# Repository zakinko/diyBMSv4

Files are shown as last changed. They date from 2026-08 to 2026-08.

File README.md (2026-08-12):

# diyBMS v4

Version 4 of the diyBMS

Do it yourself battery management system for Lithium ion battery packs/cells

More discussion [Open Energy Monitor Forum](https://community.openenergymonitor.org/c/hardware/diybms/53)

If you are looking for version 3 (obsolete) of this project take a look [here](https://github.com/stuartpittaway/diyBMS)

THIS REPOSITORY CONTAINS THE HARDWARE FOR THE SYSTEM

---

## About this branch — keeping the boards orderable

This is a fork of [stuartpittaway/diyBMSv4](https://github.com/stuartpittaway/diyBMSv4).
Every LCSC part number in every BOM here was checked against the JLCPCB parts API,
and **eight of the eleven boards could not be ordered as they stood** - parts at zero
stock, parts the API reports as discontinued, and on one board a BOM cell holding two
part numbers at once.  This branch fixes what can be fixed by changing a part number,
and says plainly where that is not enough.

**What is maintained**

* Part numbers that JLCPCB no longer stocks are replaced, where an equivalent exists
* Where the same part number also exists in the Basic library, it is used - Basic and
  Preferred parts carry no per-type setup fee
* Where no equivalent exists, the part is left alone and the reason is in the commit

**What is not**

* **Nothing here is tested on hardware.**  These are file-level changes checked
  against the schematic, the netlist, the datasheets and the parts API, and no
  further.  Reports from anyone who builds one are very welcome
* The circuits are not being redesigned.  Where a board has a weakness that needs a
  layout change - the ESP8266 controller has no decoupling capacitors at all, and no
  clamp on the ESP's RX line - it is written down, not fixed

**Two boards cannot be reproduced exactly, and are not pretended otherwise**

V440 and V450 both use AZ432 for their voltage reference.  Diodes discontinued it -
the datasheet is stamped OBSOLETE - USE AZ431L - and every SOT-23 shunt reference
still stocked is 1.240V rather than 1.250V.  On both boards that reference sets the
cell measurement, so substituting it shifts every reading by 0.8% with no warning.

D1 is therefore left as AZ432 on both.  Order the board without it and fit it by
hand; it is out of production but was made in volume and still turns up.  Anyone who
would rather have a current part than an exact V440/V450 should look at a revision
that designs AZ431L in and changes the firmware constant to match.

V400 is untouched for a different reason: its schematic carries no LCSC part numbers
at all and no BOM is generated from it.  Its parts are listed in a separate
spreadsheet, so making it orderable means building a BOM rather than editing one.

Upstream's own README follows unchanged.

---

# Videos on how to use and build

[YouTube playlist](https://youtube.com/playlist?list=PLHhwQCDPuRcZW3u0jJucsiCCsUbNbMy-c) for DIYBMS videos

[Building & ordering the PCB from JLCPCB](https://youtu.be/E1OS0ZOmOT8)

If you order a PCB, please use my affiliate link to help support this project [JLCPCB](https://jlcpcb.com/RSZ)

# Support

If you find the BMS useful, please consider buying me a beer, check out Patron for more information

https://patreon.com/StuartP

# HARDWARE

This repository contains the hardware designs, generally in KiCad format.  Unless you are changing the design, you don't need to use/install KiCad, just use the precompiled files.

The folder structure in the repository contains:

## Controller Designs
* ControllerCircuit - ESP32 controller board (newest design)
* ESP8266ControllerCircuit - [legacy] the circuit board for the legacy ESP8266 based controller

## Modules for Controller
* ModuleV490-AllInOne - Latest multi cell monitoring solution, recommended for 8 to 16S cell configurations.  No balancing, requires ModuleV490-PassiveBal passive balancer daughterboard if this is needed.
* ModuleV490-PassiveBal - daughter board for the V490 multi-cell monitoring solution, provides 200mA per cell balance current, heatsink and fan control.
* ModuleV450 - the latest SINGLE module design, using ATTINY1624 chip. Recommended for both hand soldering or mass production
* ModuleV440 - [legacy] the module circuit board V4.40, final board using ATTINY841 chip
* ModuleV400 - [legacy] the module circuit board V4.00, designed for easier hand soldering (larger parts)
* ModuleV421 - [legacy] the module circuit board V4.21, designed for mass production using JLCPCB assembly service

If you use this coupon code when you place a JLCPCB order

JLC-Stuart

and this link

https://jlcpcb.com/RSZ

you will get a discount and I get a very small amount of credit for every 30 orders, which helps to support the cost of prototyping new designs and adding new features.

### ESP32 Controller 

The latest version of the controller uses an ESP32 and supports CANBUS, RS485, SD CARD logging, relays, SSR outputs, multiple inputs, AVR programmer and much more.

Although the hardware is complete, not all features are usable from the software, this will be developed and improved over time to make use of the hardware.

[Bill of Materials](./ControllerCircuit/ComponentListBOM.md)

circuit board

### Module V4.50

The latest version of the module hardware uses the ATTINY1624 chip - part of the tinyAVR2 range.

This board requires an UPDI programmer/device - see the instructions in the code repository for how to program the boards once built.

The parts are no smaller than 0805 size (about 2mm!) which is probably the smallest size you want to attempt to hand solder.

circuit board

Specifications are similar to the V4.40 board.

### Module V4.40

V4.40 is the last board to use the ATTINY841 chip - V4.50 is the newest design if you are starting fresh.

circuit board

In addition, the hardware has a higher balance current, fuse and TVS diode to help with voltage spikes.  
Most importantly, an external crystal has been added to the micro controller (attiny841) which means the device is more reliable in low voltage situations.

The balance current for V4.40 modules is as follows:
* 1.27A at 4.2V (5.35W)
* 1.21A at 4.0V (4.84W)
* 1.13A at 3.75V (4.26W)

The module is physically larger than previous modules, this aids heat dispersal but also features a "snap off" external temperature daughter board for use in cell temperature monitoring.

You will also need to order [these parts](./ModuleV440/HandAssemblyParts.md)

# CODE/SOFTWARE

Software and code for the modules and controller can now be found in a seperate repo

For the latest controller (ESP32)
[diyBMSv4ESP32](https://github.com/stuartpittaway/diyBMSv4ESP32)

For the legacy controller (ESP8266)
[diyBMSv4Code](https://github.com/stuartpittaway/diyBMSv4Code)

# WARNING

This is a DIY product/solution so don’t use this for safety critical systems or in any situation where there could be a risk to life.  

There is no warranty, it may not work as expected or at all.

The use of this project is done so entirely at your own risk.  It may involve electrical voltages which could kill - if in doubt, seek help.

The use of this project may not be compliant with local laws or regulations - if in doubt, seek help.

# License

This work is licensed under a Creative Commons Attribution-NonCommercial-ShareAlike 2.0 UK: England & Wales License.

https://creativecommons.org/licenses/by-nc-sa/2.0/uk/

You are free to:
* Share — copy and redistribute the material in any medium or format
* Adapt — remix, transform, and build upon the material
The licensor cannot revoke these freedoms as long as you follow the license terms.

Under the following terms:
* Attribution — You must give appropriate credit, provide a link to the license, and indicate if changes were made. You may do so in any reasonable manner, but not in any way that suggests the licensor endorses you or your use.
* Non-Commercial — You may not use the material for commercial purposes.
* ShareAlike — If you remix, transform, or build upon the material, you must distribute your contributions under the same license as the original.
* No additional restrictions — You may not apply legal terms or technological measures that legally restrict others from doing anything the license permits.

Notices:
You do not have to comply with the license for elements of the material in the public domain or where your use is permitted by an applicable exception or limitation.

No warranties are given. The license may not give you all of the permissions necessary for your intended use. For example, other rights such as publicity, privacy, or moral rights may limit how you use the material.

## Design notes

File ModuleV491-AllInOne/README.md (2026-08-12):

# DIYBMS All-in-one 16S monitoring board

This is the hardware for the (up to) 16S monitoring board.

## Difference from V490

Same board, same firmware.  Only the fitted parts differ: the ones that could
no longer be ordered are replaced, and a few move to parts that cost nothing to
set up.  See the pull request that introduced this directory for the full list
and the reasoning.
This monitoring board replaces the individual cell monitoring boards used in the DIYBMS solution.  Several monitoring boards can be daisy-chained together to form larger battery packs.

You still require a DIYBMS ESP32 controller for this board to operate.

It uses an [STM32F030K6T6](https://www.st.com/en/microcontrollers-microprocessors/stm32f030k6.html) chip, with 32K flash and 4K RAM.

**WARNING**: This hardware is considered experimental & prototype, use at your own risk - it may not work as intended or at all.

## Background Information
### Software
The software for this board is available pre-compiled.  See this [link for details](https://github.com/stuartpittaway/diyBMSv4ESP32/tree/all-in-one/STM32All-In-One#readme)

Details are in the README on programming the STM32 chip for this PCB.

### KiCAD 7
This design uses KiCAD version 7.0.5.  Use the same or newer version for editing and viewing the files.  You don't need to install KiCAD if you just wish to build/order one.

### JLCPCB
The files in this repository will create a PCB and design files suitable for "almost" full construction at JLCPCB.  Some manual soldering will still be required for the connectors and cabling.

Look inside the "export" folder for the relevant production files.  You will need these files for the construction:

* module_16s_gerbers.zip
* Module_16S_bom_jlc.csv
* Module_16S_cpl_jlc.csv

Support this project by using JLCPCB referral link
https://jlcpcb.com/RSZ
when registering for the first time.

# READ THIS FIRST - IMPORTANT

Before construction of the PCB you must determine what battery cells you wish to monitor and a suitable cell voltage range.

The PCB design has options for two voltage ranges, determined by parts U2 and U6.  *ONLY ONE OF THESE CHIPS MUST BE FITTED*

The design uses a MAX14921 chip, this has a maximum of 16 cells and **65V** total battery voltage - do not exceed.

## LIFEPO4 cells up to 4.00V maximum

Use part U2, a Microchip voltage reference "MCP1501-40E/SN".  This is a 4.096V ±0.1% reference chip.

This part is available on JLCPCB as part number C1575589.

The pick and place file (CPL file) contains the part placement for this chip by default.  No further changes are required, except to double-check the order screens from JLCPCB.

Do not install part U6.

*This option has been tested by the author as working*

## Cell voltages up to 4.50V maximum

This is all 18650 style cell voltage chemistry - normally with a maximum of 4.25V.  This configuration can also be used with LIFEPO4 cells with voltages below 4.50V.

Use part U6, a Microchip voltage reference "MCP1502T-45E/CHY".   This is a 4.500V ±0.1% reference chip.

This part is NOT available from JLCPCB.  This part must be obtained from [other sources](https://www.digikey.co.uk/en/products/detail/microchip-technology/MCP1502T-45E-CHY/16549208) and **MANUALLY** soldered onto the board.  Note this is a very small chip (SOT-23-6) and difficult to solder.

Edit the pick and place (CPL file) before upload to JLCPCB to remove the line marked "U2".

Do not install part U2.

*This option has NOT been tested by the author, please feedback if you decide to experiment*

## BATTERY VOLTAGES ABOVE 24V & MINIMUM BELOW 12V

If you have an unusual Lithium cell chemistry where the maximum battery voltage is ABOVE 24V and the lowest is BELOW 12V, this monitoring board is not suitable.

## BATTERY VOLTAGES BELOW 13V (MINIMUM)

If you are building a battery whos voltage can go BELOW 13V, which typically includes 4S or 5S cell configurations.  

For example, 4S LIFEPO4 setup voltage range: 4x2.5V= 10V minimum, 4x3.65V=14.6V maximum.

Parts of the BMS circuit are not required for a battery's whos voltage can go below 13V and **must** be ommitted.  These parts operate the step-down regulator normally required for higher voltages, such as an 8S or 16S setup.   The regulator will fail to operate with an input voltage below 13V - causing the whole board to stop responding.

Ensure that the battery will not go above 24V during charging cycles.  Damage to the voltage regulator will occur if this occurs.

In this configuration, you do not require, and *MUST* not fit:

* U10 - XL7005A
* L1
* D21
* R76
* R77
* C44
* C43
* C45
* JP1/PWR 2 pin header

*Edit the pick and place and BOM files to remove any reference to the above parts, before ordering from JLCPCB*

Once these parts are removed, the board must **NEVER** be used with a battery over 24V or damage will occur.

You may want to consider fitting a smaller connector (J7) such [as this one](https://www.lcsc.com/product-detail/Pluggable-System-Terminal-Block_Ningbo-Kangnex-Elec-WJ15EDGRC-3-81-6P_C7246.html) to prevent mistakes being made.  If you do this, you will also need to add a wire between pin 6 and pin 17 of J7 on the PCB, to ensure the MAX chip receives power.

Once the board is constructed, a wire link between J9 and pin 2  (indicated by square box on silkscreen) of JP1/PWR should be made.  This connects the full battery voltage to the board and bypasses the step down circuit.

In this configuration test point "TP1" will be zero volt/not connected.

After these changes are made, if the FAN is used on the passive balancer board, this must be changed to align to the voltage of the battery - a 12V fan may no longer be suitable for example, if running at 14.6V (4S setup).

*This option has been tested by the author and confirmed working*

## PASSIVE BALANCE BOARD

The passive balance PCB is part of a seperate project folder named "ModuleV490-PassiveBal".

If you have no requirement for the passive balance board (its optional) then you can also omit the two headers marked J14 and J15 (both 22 pin) from this PCB.

## EXTERNAL TEMPERATURE SENSOR BOARD

The external temperature sensor PCB is part of a seperate project folder named "TemperaturePCB".

If you already have previous v4.50 DIYBMS monitoring boards, the same temperature sensor can be used with this design.

# CONNECTING THE ALL-IN-ONE MONITORING BOARD

Cell voltage connections are made using plugable terminal blocks.  A large 17 pin connector is connected to the most negative cell terminal, and then every positive connection to the other cells in the battery.

Ensure that you have the correct sequence of cell voltages before connecting to the BMS.  Test the pins on the plug with a multimeter to ensure the voltage continualy increases as you move up the pins (when compared to negative pin).

If you are using less than 16 cells, use wire connections between the screw terminals to link the highest cell to the remaining terminals.  For example, a 14S setup, would need a wire link between terminals 14 to 15 and 15 to 16.

The two pin plug is used to power the BMS.  This needs to be connected to the negative and positive of the battery.  Note the correct orientation of the two pins, the positive is near the edge of the board.  The silkscreen on the bottom of the PCB has the details.

Communication interface to the DIYBMS controller is via the 4 pin connector - ensure pin out is correct before connecting to the controller or damage may occur.

Important:
* Do not reverse polarity.
* Connect the 17 pin connector FIRST before connecting the power connector.
* Ensure the PRG/RUN jumper is in the RUN position for normal operation.  You will need to power cycle the board after changing modes.
* Ensure the PWR jumper is connected (except <13V setups see above).
* If the LED flashes a sequence on start up, check the software README to determine the cause
* Ensure communication interface to controller uses correct wiring orientation

# FAULT FINDING

## All cells read similar voltage (4.096V or 4.500V)

This indicates that the voltage reference is not reaching the ADC chip MCP33151.  Therefore, check voltage on TP5 and also soldering around U3 and U2/U6 depending on the V reference fitted.

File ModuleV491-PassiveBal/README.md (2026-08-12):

# DIYBMS All-in-one 16S PASSIVE BALANCE BOARD

This is the hardware for the PASSIVE BALANCE BOARD add-on to the all in one monitoring solution.

## Difference from V490

Same board, same firmware.  Only the fitted parts differ: the ones that could
no longer be ordered are replaced, and a few move to parts that cost nothing to
set up.  See the pull request that introduced this directory for the full list
and the reasoning.
**WARNING**: This hardware is considered experimental & prototype, use at your own risk - it may not work as intended or at all.

### KiCAD 7
This design uses KiCAD version 7.0.5.  Use the same or newer version for editing and viewing the files.  You don't need to install KiCAD if you just wish to build one.

### JLCPCB
This design will create a PCB and design files suitable for "almost" full construction at JLCPCB.  Some manual soldering will still be required for the connectors and cabling.

Look inside the "export" folder for the relevant production files.  You will need these files for the construction:

* module_16s_passive_gerbers.zip
* module_16s_passive_bom_jlc.csv
* module_16s_passive_cpl_jlc.csv

Support this project by using JLCPCB referral link
https://jlcpcb.com/RSZ
when registering for the first time.

# FAN

The fan is 40x40mm, 12V.  The current must be less than 150mA (0.15A).

A suitable fan is this one... 
[40mm 12V FAN](https://www.kenable.co.uk/en/peripherals/fans-cooling-devices/case-fans-other/7063-pc-case-cooling-fan-40mm-x-40mm-x-10mm-12v-012a-sleeve-bearing-10cm-007063-5055383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)

You will need to replace the power connector with a 2 pin JST PH style plug.  Cut the yellow wire off, this is not used.

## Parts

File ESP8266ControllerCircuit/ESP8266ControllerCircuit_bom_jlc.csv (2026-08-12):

Comment | Designator | Footprint | LCSC Part #
COMMS | D1 | LED_0805 | C2297
470R | R1 | R_0805_HandSoldering | C17710
2K2 | R2 | R_0805_HandSoldering | C17520
220R | R3 | R_0805_HandSoldering | C17557
4K7 | R4,R5 | R_0805_HandSoldering | C17673
EL3H7B | U2 | SOP-4_4.4x2.8mm_Pitch1.27mm | C41371267
PCF8574T/3,518 | U3 | SOIC-16W_7.5x10.3mm_Pitch1.27mm | C7605

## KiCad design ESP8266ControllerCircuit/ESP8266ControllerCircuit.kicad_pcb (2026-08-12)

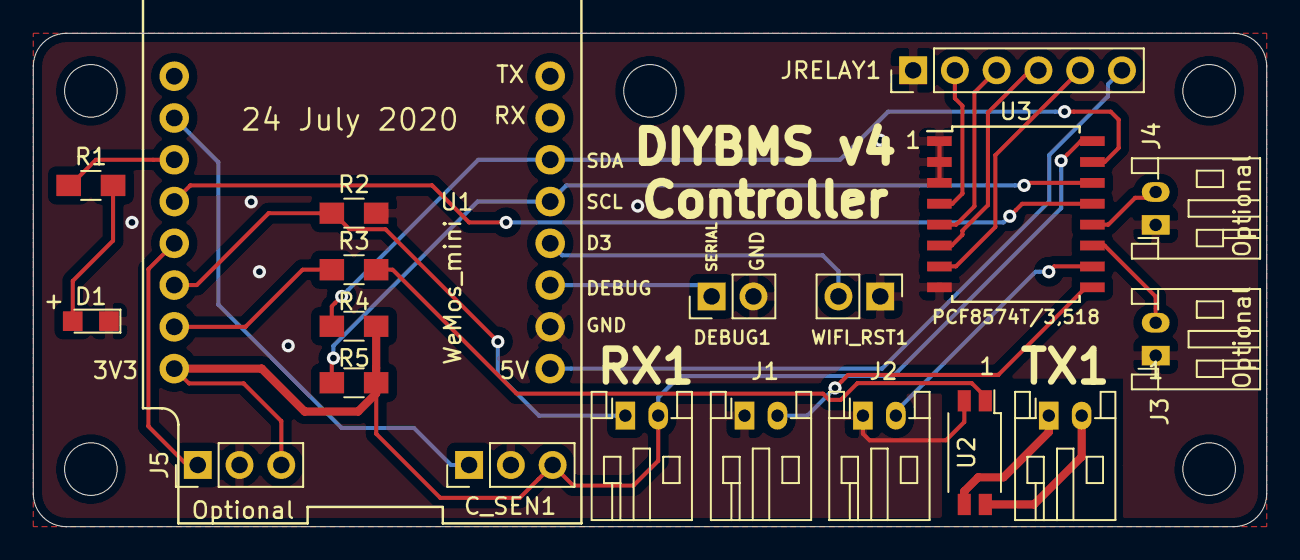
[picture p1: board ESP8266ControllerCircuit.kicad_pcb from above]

Board: 2 copper layers, 75.0 x 30.0 mm, 20 parts (0 on the bottom side), 25 nets.

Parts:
C_SEN1: Current Sensor; Pin_Header_Straight_1x03_Pitch2.54mm
D1: COMMS; LED_0805
DEBUG1: Conn_01x02_Female; Pin_Header_Straight_1x02_Pitch2.54mm
J1, J2, J3, J4: Input; JST_PH_S2B-PH-K_02x2.00mm_Angled
J5: Optional; Pin_Header_Straight_1x03_Pitch2.54mm
JRELAY1: Conn_01x06_Male; Pin_Header_Straight_1x06_Pitch2.54mm
R1: 470R; R_0805_HandSoldering
R2: 2K2; R_0805_HandSoldering
R3: 220R; R_0805_HandSoldering
R4, R5: 4K7; R_0805_HandSoldering
RX1: Receive; JST_PH_S2B-PH-K_02x2.00mm_Angled
TX1: Transmit; JST_PH_S2B-PH-K_02x2.00mm_Angled
U1: WeMos_mini; wemos-d1-mini-with-pin-header
U2: EL3H7(B)(TA)-G; SOP-4_4.4x2.8mm_Pitch1.27mm
U3: PCF8574T/3,518; SOIC-16W_7.5x10.3mm_Pitch1.27mm
WIFI_RST1: WIFI RST; Pin_Header_Straight_1x02_Pitch2.54mm

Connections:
+3V3: C_SEN1.3, J5.3, R4.1, R5.1, RX1.2, U1.16, U3.16
+5V: JRELAY1.6, U1.1
GND: C_SEN1.2, D1.1, DEBUG1.2, J1.1, J2.1, J3.1, J4.1, J5.2, JRELAY1.1, R2.1, U1.2, U2.2, U3.1, U3.2, U3.3, U3.8, WIFI_RST1.1
unnamed: C_SEN1.1, U1.10
unnamed: D1.2, R1.1
unnamed: DEBUG1.1, U1.3
unnamed: J1.2, U3.9
unnamed: J2.2, U3.10
unnamed: J3.2, U3.11
unnamed: J4.2, U3.12
unnamed: J5.1, U1.13
unnamed: JRELAY1.2, U3.4
unnamed: JRELAY1.3, U3.5
unnamed: JRELAY1.4, U3.6
unnamed: JRELAY1.5, U3.7
unnamed: R1.2, U1.11
unnamed: R2.2, RX1.1, U1.14
unnamed: R3.1, U2.1
unnamed: R3.2, U1.15
unnamed: TX1.1, U2.3
unnamed: TX1.2, U2.4
unnamed: U1.4, WIFI_RST1.2
PCFINT: U1.12, U3.13
SCL: R5.2, U1.5, U3.14
SDA: R4.2, U1.6, U3.15

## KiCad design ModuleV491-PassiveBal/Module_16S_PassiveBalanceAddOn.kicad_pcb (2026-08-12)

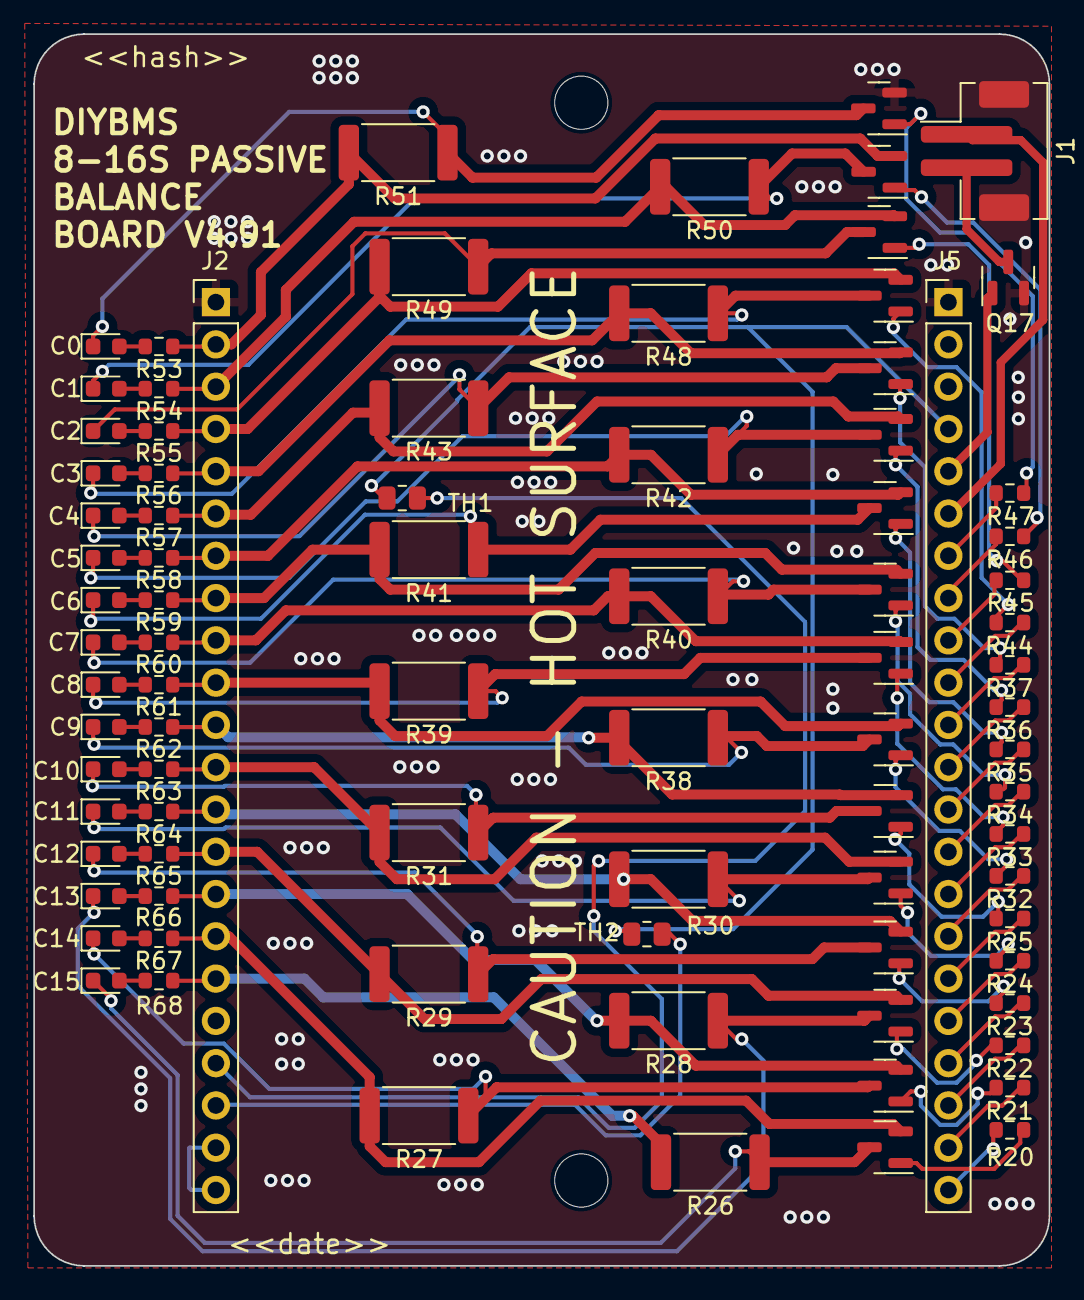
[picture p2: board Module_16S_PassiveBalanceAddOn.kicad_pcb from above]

Board: 2 copper layers, 61.0 x 74.0 mm, 89 parts (1 on the bottom side), 88 nets.

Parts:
C0, C1, C2, C3, C4, C5, C6, C7, C8, C9, C10, C11, C12, C13, C14, C15: Yellow; LED_0603_1608Metric
G2: DIYBMS_LOGO; diybms_logo_24x10mm
H1, H2: MountingHole; MountingHole_3.2mm_M3
J1: FAN_12V; JST_PH_B2B-PH-SM4-TB_1x02-1MP_P2.00mm_Vertical
J2, J5: 22PIN; PinHeader_1x22_P2.54mm_Vertical
Q1, Q2, Q3, Q4, Q5, Q6, Q7, Q8, Q9, Q10, Q11, Q12, Q13, Q14, Q15, Q16: AO3400A; SOT-23
Q17: SZNUD3160; SOT-23
R20, R21, R22, R23, R24, R25, R32, R33, R34, R35, R36, R37, R44, R45, R46, R47: 100R; R_0603_1608Metric
R26, R27, R28, R29, R30, R31, R38, R39, R40, R41, R42, R43, R48, R49, R50, R51: 18R 2W; R_2512_6332Metric
R53, R54, R55, R56, R57, R58, R59, R60, R61, R62, R63, R64, R65, R66, R67, R68: 330R; R_0603_1608Metric
TH1, TH2: 10K NTC; R_0805_2012Metric

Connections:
+3.3V: J2.21, J2.22
BA1: J5.7, R47.1
BA2: J5.8, R46.1
BA3: J5.9, R45.1
BA4: J5.10, R44.1
BA5: J5.11, R37.1
BA6: J5.12, R36.1
BA7: J5.13, R35.1
BA8: J5.14, R34.1
BA9: J5.15, R33.1
BA10: J5.16, R32.1
BA11: J5.17, R25.1
BA12: J5.18, R24.1
BA13: J5.19, R23.1
BA14: J5.20, R22.1
BA15: J5.21, R21.1
BA16: J5.22, R20.1
CV1: J2.2, Q15.2 (S), R51.2, R53.1
CV2: J2.3, Q14.2 (S), R50.2, R54.1
CV3: J2.4, Q13.2 (S), R49.2, R55.1
CV4: J2.5, Q12.2 (S), R48.2, R56.1
CV5: J2.6, Q11.2 (S), R43.2, R57.1
CV6: J2.7, Q10.2 (S), R42.2, R58.1
CV7: J2.8, Q9.2 (S), R41.2, R59.1
CV8: J2.9, Q8.2 (S), R40.2, R60.1
CV9: J2.10, Q7.2 (S), R39.2, R61.1
CV10: J2.11, Q6.2 (S), R38.2, R62.1
CV11: J2.12, Q5.2 (S), R31.2, R63.1
CV12: J2.13, Q4.2 (S), R30.2, R64.1
CV13: J2.14, Q3.2 (S), R29.2, R65.1
CV14: J2.15, Q2.2 (S), R28.2, R66.1
CV15: J2.16, Q1.2 (S), R27.2, R67.1
CV16: J2.17, R26.2, R68.1
FAN: J5.5, Q17.1 (G)
GND: J1.MP, J2.1, J5.1, Q16.2 (S), Q17.2 (S)
unnamed: C0.2 (A), R53.2
unnamed: C0.1 (K), Q16.3 (D), R51.1
unnamed: C1.2 (A), R54.2
unnamed: C1.1 (K), Q15.3 (D), R50.1
unnamed: C2.2 (A), R55.2
unnamed: C2.1 (K), Q14.3 (D), R49.1
unnamed: C3.2 (A), R56.2
unnamed: C3.1 (K), Q13.3 (D), R48.1
unnamed: C4.2 (A), R57.2
unnamed: C4.1 (K), Q12.3 (D), R43.1
unnamed: C5.2 (A), R58.2
unnamed: C5.1 (K), Q11.3 (D), R42.1
unnamed: C6.2 (A), R59.2
unnamed: C6.1 (K), Q10.3 (D), R41.1
unnamed: C7.2 (A), R60.2
unnamed: C7.1 (K), Q9.3 (D), R40.1
unnamed: C8.2 (A), R61.2
unnamed: C8.1 (K), Q8.3 (D), R39.1
unnamed: C9.2 (A), R62.2
unnamed: C9.1 (K), Q7.3 (D), R38.1
unnamed: C10.2 (A), R63.2
unnamed: C10.1 (K), Q6.3 (D), R31.1
unnamed: C11.2 (A), R64.2
unnamed: C11.1 (K), Q5.3 (D), R30.1
unnamed: C12.2 (A), R65.2
unnamed: C12.1 (K), Q4.3 (D), R29.1
unnamed: C13.2 (A), R66.2
unnamed: C13.1 (K), Q3.3 (D), R28.1
unnamed: C14.2 (A), R67.2
unnamed: C14.1 (K), Q2.3 (D), R27.1
unnamed: C15.2 (A), R68.2
unnamed: C15.1 (K), Q1.3 (D), R26.1
unnamed: J1.2, Q17.3 (D)
unnamed: Q1.1 (G), R20.2
unnamed: Q2.1 (G), R21.2
unnamed: Q3.1 (G), R22.2
unnamed: Q4.1 (G), R23.2
unnamed: Q5.1 (G), R24.2
unnamed: Q6.1 (G), R25.2
unnamed: Q7.1 (G), R32.2
unnamed: Q8.1 (G), R33.2
unnamed: Q9.1 (G), R34.2
unnamed: Q10.1 (G), R35.2
unnamed: Q11.1 (G), R36.2
unnamed: Q12.1 (G), R37.2
unnamed: Q13.1 (G), R44.2
unnamed: Q14.1 (G), R45.2
unnamed: Q15.1 (G), R46.2
unnamed: Q16.1 (G), R47.2
STEP_DOWN_V: J1.1, J5.6
T1: J2.19, TH1.2
T2: J2.20, TH2.2
TH_ENABLE: J5.4, TH1.1, TH2.1

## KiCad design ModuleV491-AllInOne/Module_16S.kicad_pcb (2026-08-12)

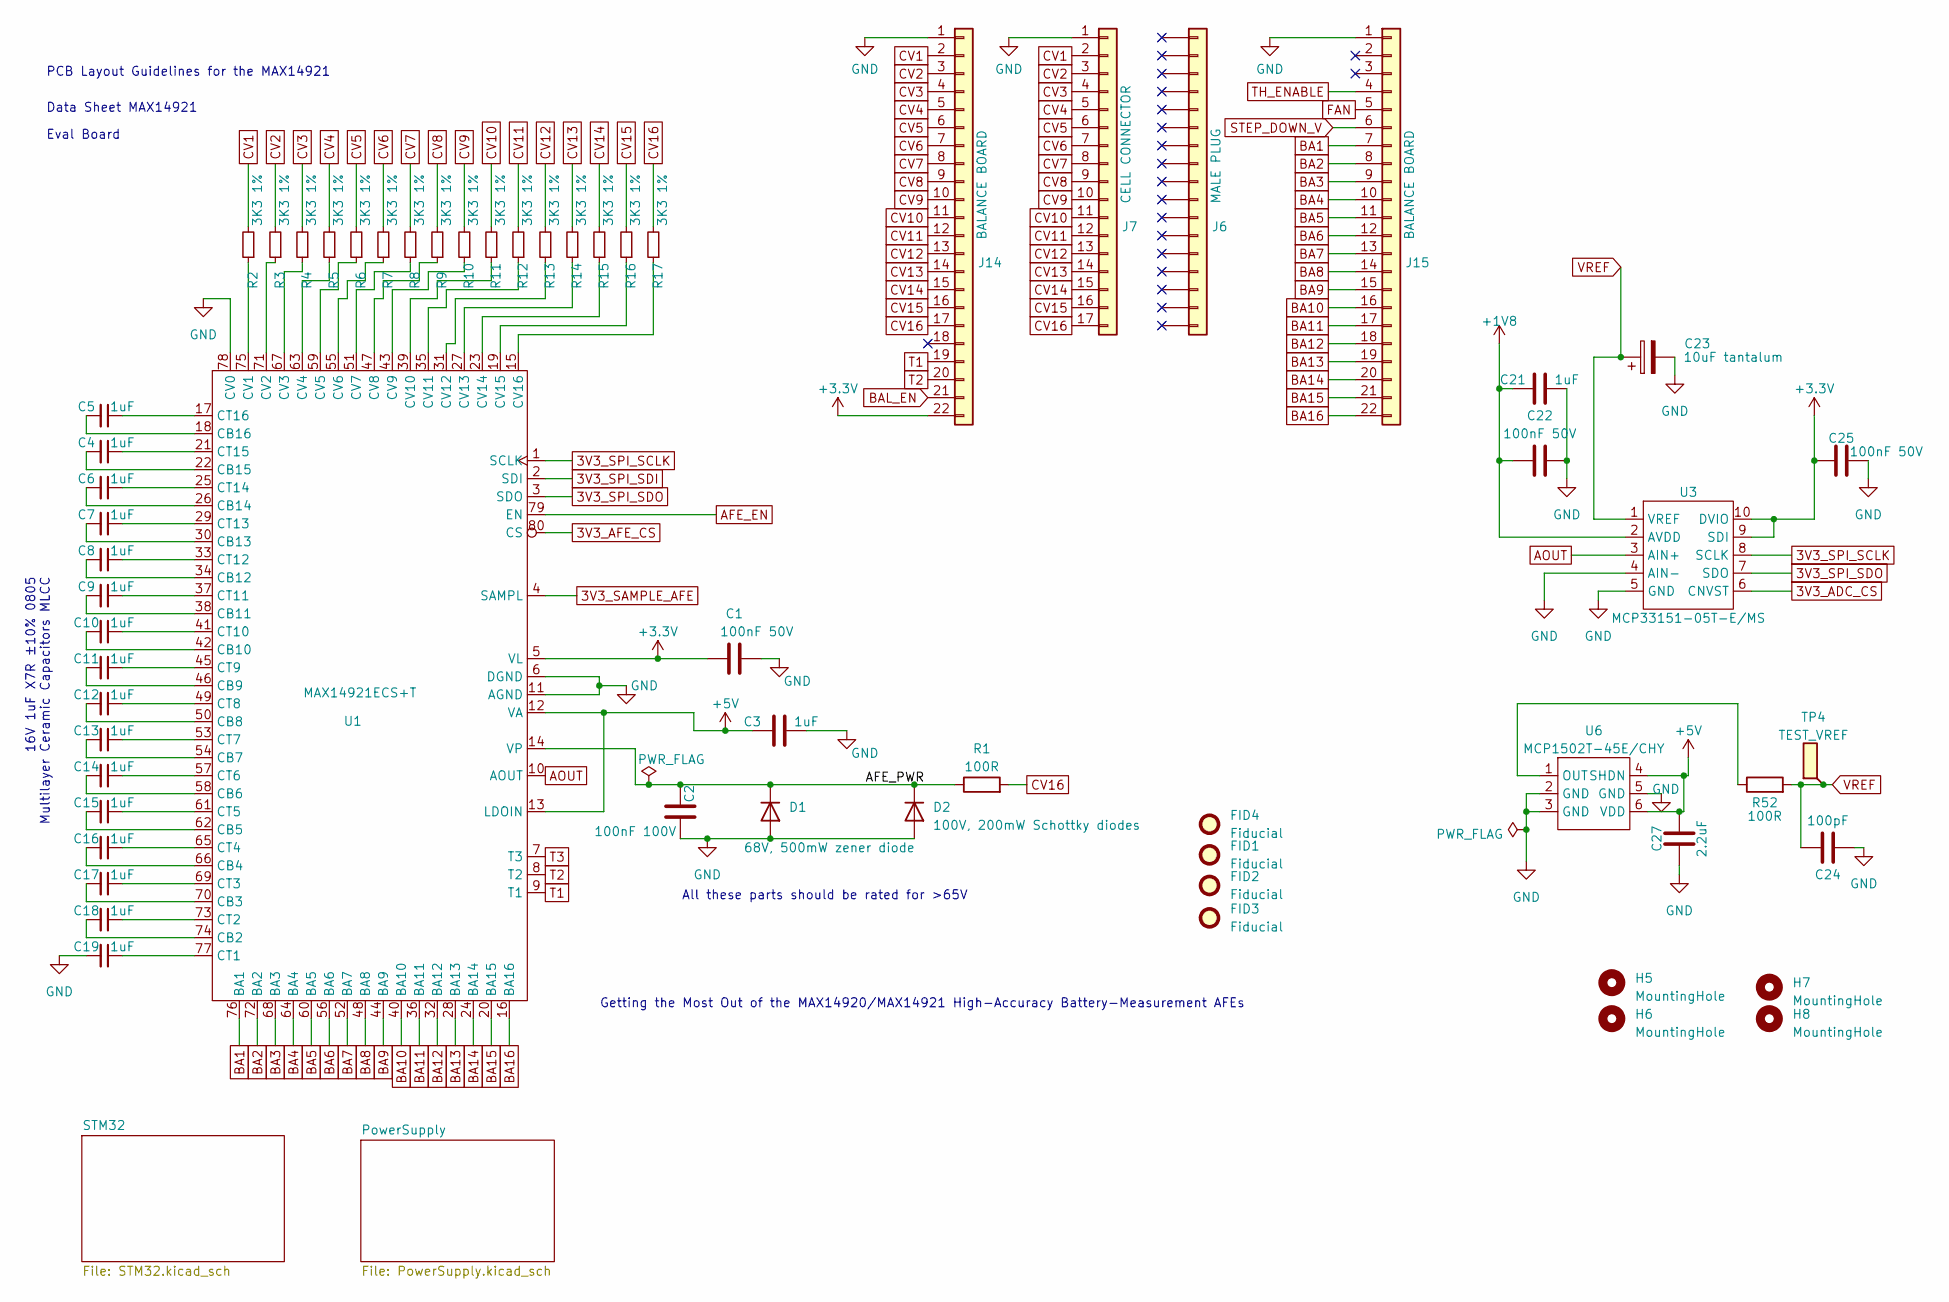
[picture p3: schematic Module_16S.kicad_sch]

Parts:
C1, C22, C25: 100nF 50V; C_0603_1608Metric; PartNumber CC0603KRX7R9BB104; LCSCStockCode C14663
C2: 100nF 100V; C_0805_2012Metric; PartNumber CL21B104KCFNNNE; LCSCStockCode C28233
C3, C4, C5, C6, C7, C8, C9, C10, C11, C12, C13, C14, C15, C16, C17, C18, C19, C21: 1uF; C_0805_2012Metric; PartNumber CL21B105KBFNNNE; LCSCStockCode C28323
C23: 10uF tantalum; CP_EIA-3216-18_Kemet-A; PartNumber TAJA106K016RNJ; LCSCStockCode C7171
C24: 100pF; C_0603_1608Metric; PartNumber CL10C101JB8NNNC; LCSCStockCode C14858
C27: 2.2uF; C_0603_1608Metric; PartNumber CL10A225KO8NNNC; LCSCStockCode C23630
D1: 68V, 500mW zener diode; D_SOD-123; PartNumber MMSZ5266BT1G; LCSCStockCode C242416
D2: 100V, 200mW Schottky diodes; D_SOD-123; PartNumber BAT46W-7-F; LCSCStockCode C83152
FID1, FID2, FID3, FID4: Fiducial; Fiducial_1.5mm_Mask3mm
H5, H6, H7, H8: MountingHole; MountingHole_3.2mm_M3_ISO7380
J6: MALE PLUG; PartNumber DB2EK-3.81-17P-GN-S; LCSCStockCode C430370
J7: CELL CONNECTOR; WJ15EDGRC-3.81-17P; PartNumber DB2ERC-3.81-17P-GN; LCSCStockCode C430372
J14, J15: BALANCE BOARD; PinSocket_1x22_P2.54mm_Vertical; PartNumber CS-1165SDIG-1*22; LCSCStockCode C2886702
R1, R52: 100R; R_0603_1608Metric; PartNumber 0603WAF1000T5E; LCSCStockCode C22775
R2, R3, R4, R5, R6, R7, R8, R9, R10, R11, R12, R13, R14, R15, R16, R17: 3K3 1%; R_0603_1608Metric; PartNumber 0603WAF3301T5E; LCSCStockCode C22978
TP4: TEST_VREF; TestPoint_Pad_1.5x1.5mm
U1: MAX14921ECS+T; TQFP-80_12x12mm_P0.5mm; PartNumber MAX14921ECS+T; LCSCStockCode C2932577
U3: MCP33151-05T-E/MS; MSOP-10_3x3mm_P0.5mm; PartNumber MCP33151-05T-E/MS; LCSCStockCode C627094
U6: MCP1502T-45E/CHY; SOT-23-6; PartNumber MCP1502T-45E/CHY; LCSCStockCode C5236158

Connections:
3V3_ADC_CS: U3.6 (CNVST); also elsewhere on the board
3V3_AFE_CS: U1.80 (CS); also elsewhere on the board
3V3_SAMPLE_AFE: U1.4 (SAMPL); also elsewhere on the board
3V3_SPI_SCLK: U1.1 (SCLK), U3.8 (SCLK); also elsewhere on the board
3V3_SPI_SDI: U1.2 (SDI); also elsewhere on the board
3V3_SPI_SDO: U1.3 (SDO), U3.7 (SDO); also elsewhere on the board
AFE_EN: U1.79 (EN); also elsewhere on the board
AOUT: U1.10 (AOUT), U3.3 (AIN+)
BA1: J15.7, U1.76 (BA1)
BA2: J15.8, U1.72 (BA2)
BA3: J15.9, U1.68 (BA3)
BA4: J15.10, U1.64 (BA4)
BA5: J15.11, U1.60 (BA5)
BA6: J15.12, U1.56 (BA6)
BA7: J15.13, U1.52 (BA7)
BA8: J15.14, U1.48 (BA8)
BA9: J15.15, U1.44 (BA9)
BA10: J15.16, U1.40 (BA10)
BA11: J15.17, U1.36 (BA11)
BA12: J15.18, U1.32 (BA12)
BA13: J15.19, U1.28 (BA13)
BA14: J15.20, U1.24 (BA14)
BA15: J15.21, U1.20 (BA15)
BA16: J15.22, U1.16 (BA16)
BAL_EN: J14.21; also elsewhere on the board
CV1: J7.2, J14.2, R2.2
CV2: J7.3, J14.3, R3.2
CV3: J7.4, J14.4, R4.2
CV4: J7.5, J14.5, R5.2
CV5: J7.6, J14.6, R6.2
CV6: J7.7, J14.7, R7.2
CV7: J7.8, J14.8, R8.2
CV8: J7.9, J14.9, R9.2
CV9: J7.10, J14.10, R10.2
CV10: J7.11, J14.11, R11.2
CV11: J7.12, J14.12, R12.2
CV12: J7.13, J14.13, R13.2
CV13: J7.14, J14.14, R14.2
CV14: J7.15, J14.15, R15.2
CV15: J7.16, J14.16, R16.2
FAN: J15.5; also elsewhere on the board
unnamed: C18.2, U1.74 (CB2)
unnamed: C17.2, U1.70 (CB3)
unnamed: C16.2, U1.66 (CB4)
unnamed: C15.2, U1.62 (CB5)
unnamed: C14.2, U1.58 (CB6)
unnamed: C13.2, U1.54 (CB7)
unnamed: C12.2, U1.50 (CB8)
unnamed: C11.2, U1.46 (CB9)
unnamed: C10.2, U1.42 (CB10)
unnamed: C9.2, U1.38 (CB11)
unnamed: C8.2, U1.34 (CB12)
unnamed: C7.2, U1.30 (CB13)
unnamed: C6.2, U1.26 (CB14)
unnamed: C4.2, U1.22 (CB15)
unnamed: C5.2, U1.18 (CB16)
unnamed: C19.1, U1.77 (CT1)
unnamed: C18.1, U1.73 (CT2)
unnamed: C17.1, U1.69 (CT3)
unnamed: C16.1, U1.65 (CT4)
unnamed: C15.1, U1.61 (CT5)
unnamed: C14.1, U1.57 (CT6)
unnamed: C13.1, U1.53 (CT7)
unnamed: C12.1, U1.49 (CT8)
unnamed: C11.1, U1.45 (CT9)
unnamed: C10.1, U1.41 (CT10)
unnamed: C9.1, U1.37 (CT11)
unnamed: C8.1, U1.33 (CT12)
unnamed: C7.1, U1.29 (CT13)
unnamed: C6.1, U1.25 (CT14)
unnamed: C4.1, U1.21 (CT15)
unnamed: C5.1, U1.17 (CT16)
unnamed: R2.1, U1.75 (CV1)
unnamed: R3.1, U1.71 (CV2)
unnamed: R4.1, U1.67 (CV3)
unnamed: R5.1, U1.63 (CV4)
unnamed: R6.1, U1.59 (CV5)
unnamed: R7.1, U1.55 (CV6)
unnamed: R8.1, U1.51 (CV7)
unnamed: R9.1, U1.47 (CV8)
unnamed: R10.1, U1.43 (CV9)
unnamed: R11.1, U1.39 (CV10)
unnamed: R12.1, U1.35 (CV11)
unnamed: R13.1, U1.31 (CV12)
unnamed: R14.1, U1.27 (CV13)
unnamed: R15.1, U1.23 (CV14)
unnamed: R16.1, U1.19 (CV15)
unnamed: R17.1, U1.15 (CV16)
unnamed: R52.1, U6.1 (OUT)
STEP_DOWN_V: J15.6; also elsewhere on the board
T1: J14.19, U1.9 (T1); also elsewhere on the board
TH_ENABLE: J15.4; also elsewhere on the board

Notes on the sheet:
All these parts should be rated for >65V
Getting the Most Out of the MAX14920/MAX14921 High-Accuracy Battery-Measurement AFEs
Eval Board
16V 1uF X7R ±10% 0805 Multilayer Ceramic Capacitors MLCC
Data Sheet MAX14921
PCB Layout Guidelines for the MAX14921

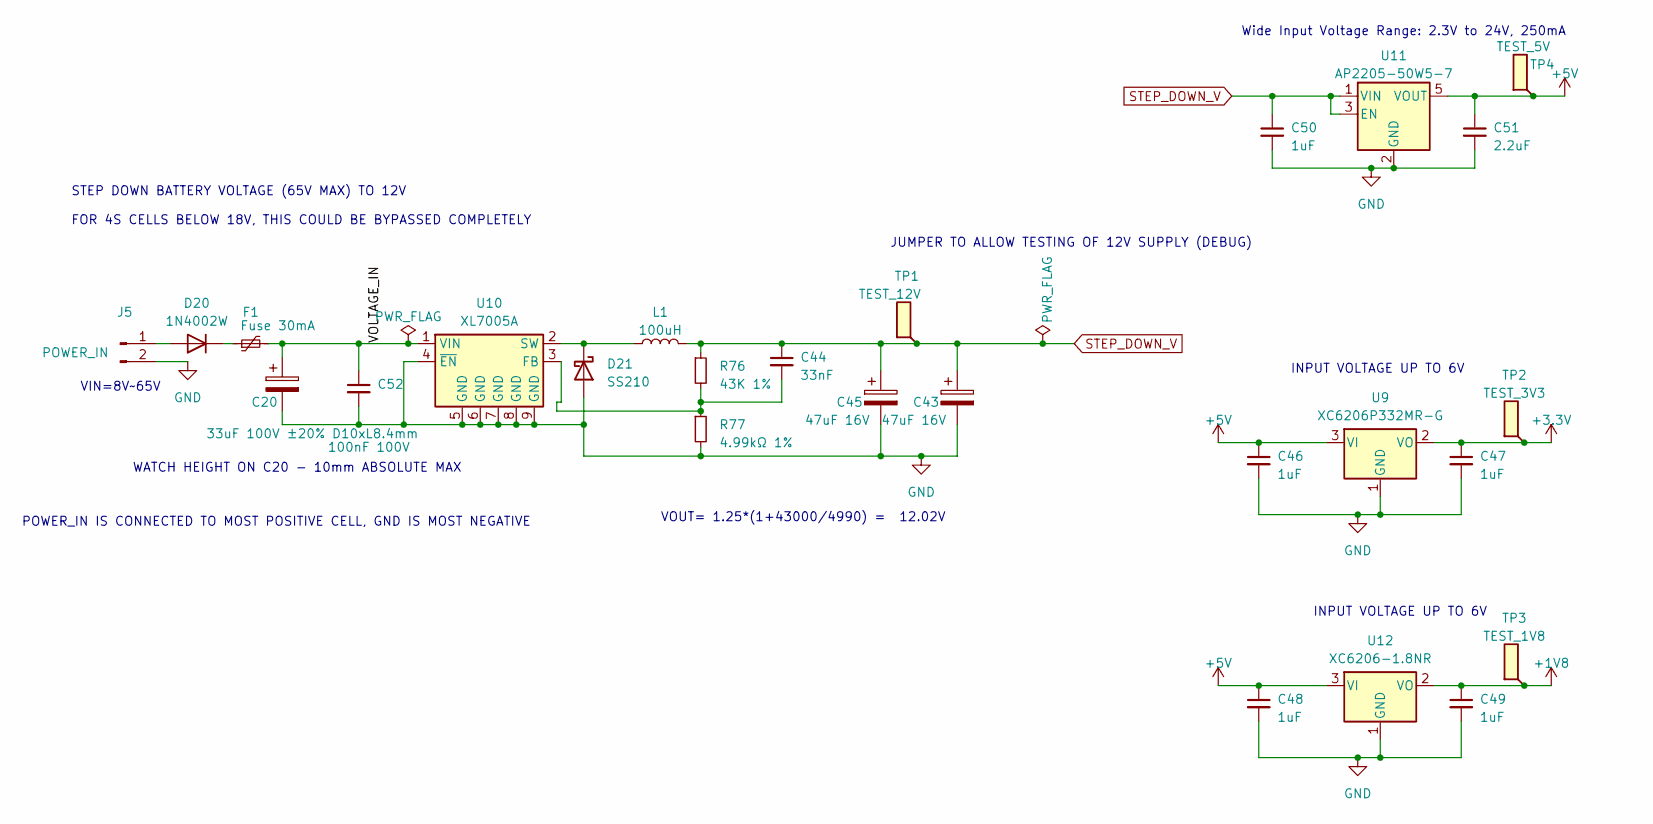
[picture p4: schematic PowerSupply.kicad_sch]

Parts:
C20: 33uF 100V ±20% D10xL8.4mm; CP_Elec_10x7.9; PartNumber VK7E0842A330MV; LCSCStockCode C486954
C43, C45: 47uF 16V; CP_Elec_5x5.4; PartNumber RVT1C470M0505; LCSCStockCode C3337
C44: 33nF; C_0603_1608Metric; PartNumber CL10B333KB8NNNC; LCSCStockCode C21117
C46, C47, C48, C49, C50: 1uF; C_0805_2012Metric; PartNumber CL21B105KBFNNNE; LCSCStockCode C28323
C51: 2.2uF; C_0603_1608Metric; PartNumber CL10A225KO8NNNC; LCSCStockCode C23630
C52: 100nF 100V; C_0805_2012Metric; PartNumber CL21B104KCFNNNE; LCSCStockCode C28233
D20: 1N4002W; D_SOD-123F; PartNumber 1N4002W; LCSCStockCode C169542
D21: SS210; D_SMA; PartNumber SS210; LCSCStockCode C14996
F1: Fuse 30mA; Fuse_0805_2012Metric; PartNumber 0805L003/80XR; LCSCStockCode C19273358
J5: POWER_IN; PhoenixContact_MC_1,5_2-G-3.81_1x02_P3.81mm_Horizontal; PartNumber WJ15EDGRC-3.81-2P; LCSCStockCode C8387
L1: 100uH; L_1008_2520Metric_Pad1.43x2.20mm_HandSolder; PartNumber NLV25T-101J-PF; LCSCStockCode C76826
R76: 43K 1%; R_0603_1608Metric; PartNumber 0603WAF4302T5E; LCSCStockCode C23172
R77: 4.99kΩ 1%; R_0603_1608Metric; PartNumber 0603WAF4991T5E; LCSCStockCode C23046
TP1: TEST_12V; TestPoint_Pad_1.5x1.5mm
TP2: TEST_3V3; TestPoint_Pad_1.5x1.5mm
TP3: TEST_1V8; TestPoint_Pad_1.5x1.5mm
TP4: TEST_5V; TestPoint_Pad_1.5x1.5mm
U9: XC6206P332MR-G; SOT-23-3; PartNumber XC6206P332MR-G; LCSCStockCode C5446
U10: XL7005A; SOIC-8-1EP_3.9x4.9mm_P1.27mm_EP2.29x3mm; PartNumber XL7005A; LCSCStockCode C50848
U11: AP2205-50W5-7; SOT-23-5; PartNumber AP2205-50W5-7; LCSCStockCode C5378676
U12: XC6206-1.8NR; SOT-23-3; PartNumber XC6206-1.8NR; LCSCStockCode C2984870

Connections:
/PowerSupply/VOLTAGE_IN: C20.1, C52.1, F1.2, U10.1 (VIN)
unnamed: D20.2 (A), J5.1
unnamed: D20.1 (K), F1.1
unnamed: D21.1 (K), L1.1, U10.2 (SW)
unnamed: C44.2, R76.2, R77.1, U10.3 (FB)
STEP_DOWN_V: C43.1, C44.1, C45.1, C50.1, L1.2, R76.1, TP1.1, U11.1 (VIN), U11.3 (EN); also elsewhere on the board

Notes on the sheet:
INPUT VOLTAGE UP TO 6V
POWER_IN IS CONNECTED TO MOST POSITIVE CELL, GND IS MOST NEGATIVE
JUMPER TO ALLOW TESTING OF 12V SUPPLY (DEBUG)
VIN=8V~65V
STEP DOWN BATTERY VOLTAGE (65V MAX) TO 12V FOR 4S CELLS BELOW 18V, THIS COULD BE BYPASSED COMPLETELY
WATCH HEIGHT ON C20 - 10mm ABSOLUTE MAX
VOUT= 1.25*(1+43000/4990) = 12.02V
Wide Input Voltage Range: 2.3V to 24V, 250mA

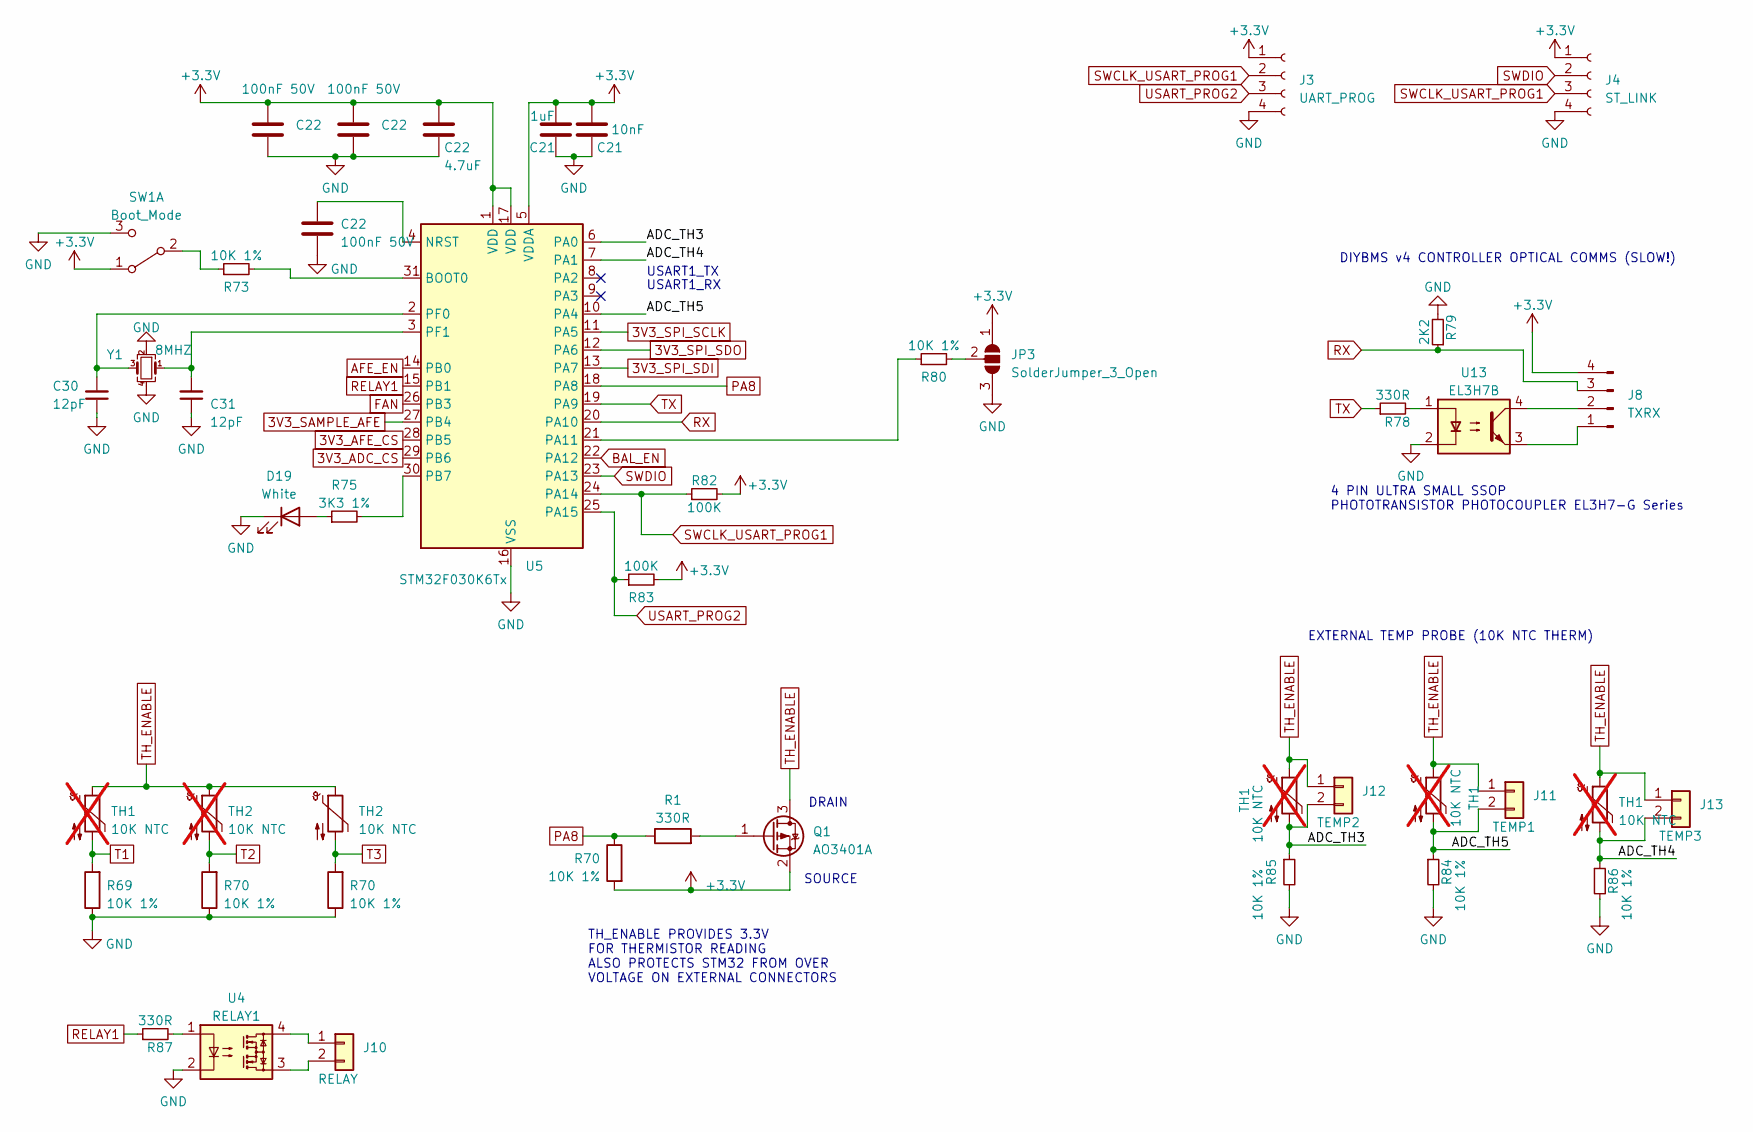
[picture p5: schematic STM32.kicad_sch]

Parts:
C21: 1uF; C_0805_2012Metric; PartNumber CL21B105KBFNNNE; LCSCStockCode C28323
C22: 100nF 50V; C_0603_1608Metric; PartNumber CC0603KRX7R9BB104; LCSCStockCode C14663
C30, C31: 12pF; C_0402_1005Metric; PartNumber 0402CG120J500NT; LCSCStockCode C1547
D19: White; LED_0603_1608Metric; LCSCStockCode C2290
J3: UART_PROG; PinSocket_1x04_P2.54mm_Horizontal; PartNumber PM254-1-04-W-8.5; LCSCStockCode C2897386
J4: ST_LINK; PinSocket_1x04_P2.54mm_Horizontal; PartNumber PM254-1-04-W-8.5; LCSCStockCode C2897386
J8: TXRX; PhoenixContact_MC_1,5_4-G-3.81_1x04_P3.81mm_Horizontal; PartNumber WJ15EDGRC-3.81-4P; LCSCStockCode C7245
J10: RELAY; JST_PH_S2B-PH-SM4-TB_1x02-1MP_P2.00mm_Horizontal; PartNumber S2B-PH-SM4-TB(LF)(SN); LCSCStockCode C295747
J11: TEMP1; JST_PH_S2B-PH-SM4-TB_1x02-1MP_P2.00mm_Horizontal; PartNumber S2B-PH-SM4-TB(LF)(SN); LCSCStockCode C295747
J12: TEMP2; JST_PH_S2B-PH-SM4-TB_1x02-1MP_P2.00mm_Horizontal; PartNumber S2B-PH-SM4-TB(LF)(SN); LCSCStockCode C295747
J13: TEMP3; JST_PH_S2B-PH-SM4-TB_1x02-1MP_P2.00mm_Horizontal; PartNumber S2B-PH-SM4-TB(LF)(SN); LCSCStockCode C295747
JP3: SolderJumper_3_Open; SolderJumper-3_P1.3mm_Open_Pad1.0x1.5mm_NumberLabels
Q1: AO3401A; SOT-23; PartNumber AO3401A; LCSCStockCode C15127
R1, R78, R87: 330R; R_0603_1608Metric; PartNumber 0603WAF3300T5E; LCSCStockCode C23138
R69, R70, R73, R80, R84, R85, R86: 10K 1%; R_0603_1608Metric; PartNumber 0603WAF1002T5E; LCSCStockCode C25804
R75: 3K3 1%; R_0603_1608Metric; PartNumber 0603WAF3301T5E; LCSCStockCode C22978
R79: 2K2; R_0603_1608Metric; PartNumber 0603WAF2201T5E; LCSCStockCode C4190
R82, R83: 100K; R_0603_1608Metric; PartNumber 0603WAF1003T5E; LCSCStockCode C25803
SW1: Boot_Mode; MST22D18G2 125; LCSCStockCode C2906280
TH1: 10K NTC; R_0805_2012Metric; PartNumber CMFB103F3950FANT; LCSCStockCode C51597; not fitted
TH2: 10K NTC; R_0805_2012Metric; PartNumber CMFB103F3950FANT; LCSCStockCode C51597
U4: RELAY1; SO-4_4.4x4.3mm_P2.54mm; PartNumber LT219-1; LCSCStockCode C2691601
U5: STM32F030K6Tx; LQFP-32_7x7mm_P0.8mm; PartNumber STM32F030K6T6; LCSCStockCode C46830
U13: EL3H7B; SOP-4_4.4x2.6mm_P1.27mm; PartNumber EL3H7B; LCSCStockCode C41371267
Y1: 8MHZ; Crystal_SMD_3225-4Pin_3.2x2.5mm; PartNumber TAXM8M4RDBCCT2T; LCSCStockCode C400090

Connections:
3V3_ADC_CS: U5.29 (PB6); also elsewhere on the board
3V3_AFE_CS: U5.28 (PB5); also elsewhere on the board
3V3_SAMPLE_AFE: U5.27 (PB4); also elsewhere on the board
3V3_SPI_SCLK: U5.11 (PA5); also elsewhere on the board
3V3_SPI_SDI: U5.13 (PA7); also elsewhere on the board
3V3_SPI_SDO: U5.12 (PA6); also elsewhere on the board
/STM32/ADC_TH3: J12.2, R85.1, TH1.2, U5.6 (PA0)
/STM32/ADC_TH4: J13.2, R86.1, TH1.2, U5.7 (PA1)
/STM32/ADC_TH5: J11.2, R84.1, TH1.2, U5.10 (PA4)
AFE_EN: U5.14 (PB0); also elsewhere on the board
BAL_EN: U5.22 (PA12); also elsewhere on the board
FAN: U5.26 (PB3); also elsewhere on the board
unnamed: D19.2 (A), R75.1
unnamed: J8.1, U13.3
unnamed: J8.2, U13.4
unnamed: J10.1, U4.4
unnamed: J10.2, U4.3
unnamed: JP3.2 (C), R80.2
unnamed: R78.2, U13.1
unnamed: R87.2, U4.1
unnamed: R73.1, SW1.2 (B)
unnamed: R73.2, U5.31 (BOOT0)
unnamed: R80.1, U5.21 (PA11)
unnamed: R75.2, U5.30 (PB7)
unnamed: C30.2, U5.2 (PF0), Y1.3
unnamed: C31.2, U5.3 (PF1), Y1.1
RELAY1: R87.1, U5.15 (PB1)
RX: J8.3, R79.1, U5.20 (PA10)
SWCLK_USART_PROG1: J3.2, J4.3, R82.1, U5.24 (PA14)
SWDIO: J4.2, U5.23 (PA13)
T1: R69.2, TH1.2; also elsewhere on the board
TH_ENABLE: J11.1, J12.1, J13.1, Q1.3 (D), TH1.1, TH2.1; also elsewhere on the board
TX: R78.1, U5.19 (PA9)
USART_PROG2: J3.3, R83.1, U5.25 (PA15)

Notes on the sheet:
4 PIN ULTRA SMALL SSOP PHOTOTRANSISTOR PHOTOCOUPLER EL3H7-G Series
SOURCE
USART1_RX
DIYBMS v4 CONTROLLER OPTICAL COMMS (SLOW!)
TH_ENABLE PROVIDES 3.3V FOR THERMISTOR READING ALSO PROTECTS STM32 FROM OVER VOLTAGE ON EXTERNAL CONNECTORS
DRAIN
EXTERNAL TEMP PROBE (10K NTC THERM)
USART1_TX

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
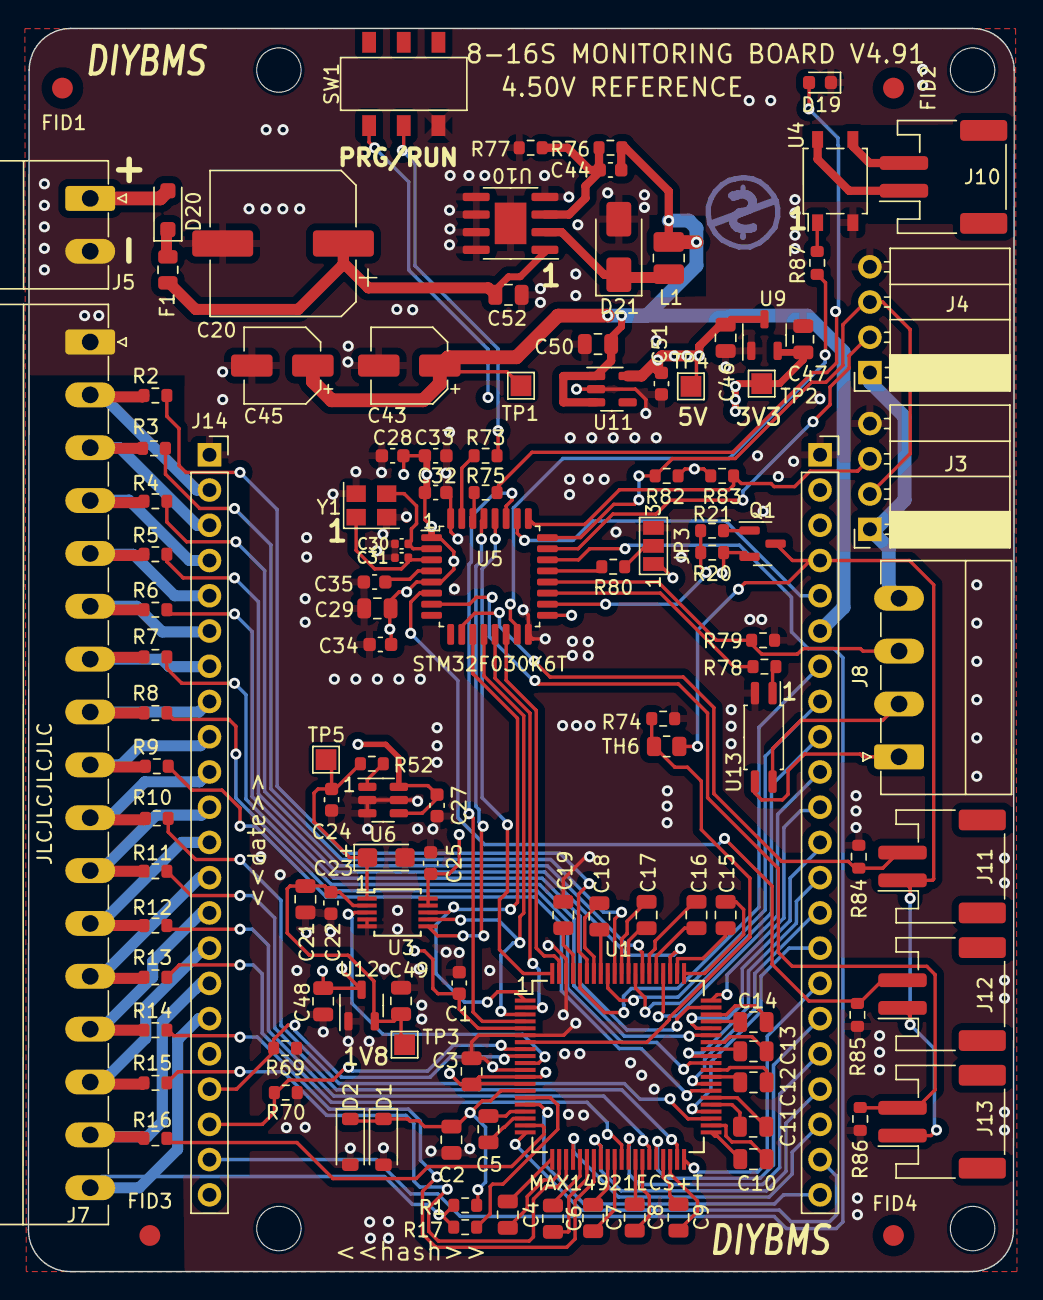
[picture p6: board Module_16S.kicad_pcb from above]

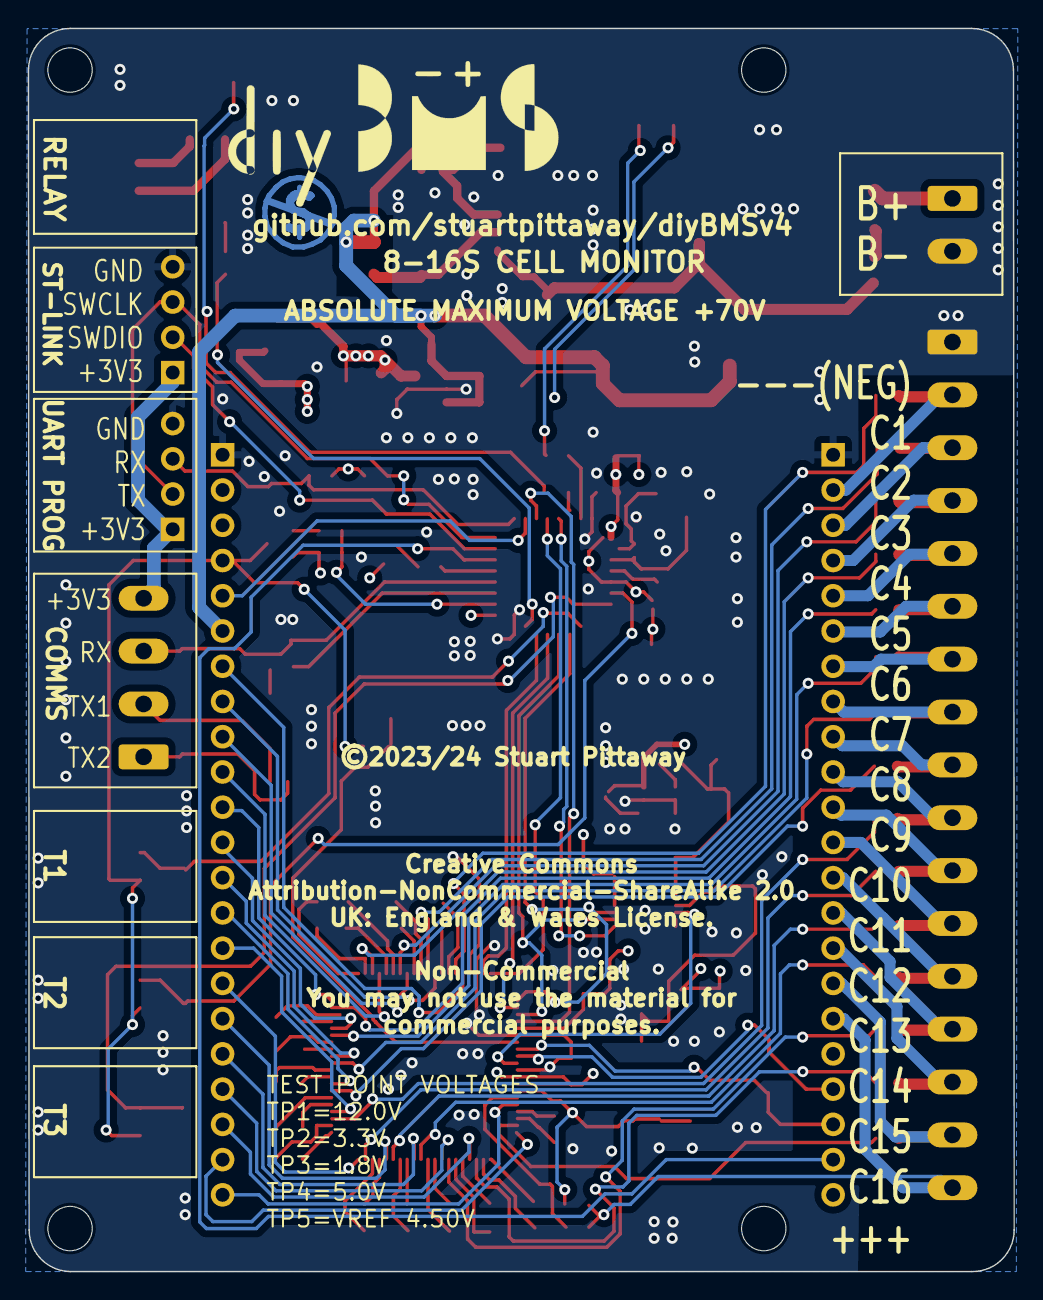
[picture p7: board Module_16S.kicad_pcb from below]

Board: 4 copper layers, 71.1 x 89.6 mm, 128 parts (2 on the bottom side), 132 nets.

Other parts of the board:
C28, C32, C35: 100nF 50V; C_0603_1608Metric
C29: 1uF; C_0805_2012Metric
C33: 4.7uF; C_0603_1608Metric
C34: 10nF; C_0603_1608Metric
R20, R74: 10K 1%; R_0603_1608Metric
R21: 330R; R_0603_1608Metric
SYM01: Symbol_CC-Noncommercial_CopperTop_Small
SYM02: LOGO; diybms_logo_24x10mm
TH6: 10K NTC; R_0805_2012Metric
TP5: TEST_VREF; TestPoint_Pad_1.5x1.5mm

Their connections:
TH_ENABLE: TH6.1; also elsewhere on the board

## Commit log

2026-08-11 V490 README describes a voltage reference that is not on the board
    The "READ THIS FIRST" section presents U2 and U6 as a choice of voltage
    reference, one of which must be fitted. U2 is not in the design:
    grep -c '"U2"' Module_16S.kicad_sch / PowerSupply.kicad_sch / STM32.kicad_sch -> 0 / 0 / 0
    grep -c '"U2"' Module_16S.kicad_pcb -> 0
    grep -c 'MCP1501' any of the above, plus the BOM and CPL -> 0
    symbol libraries: mcp1502t-45e.kicad_sym (no MCP1501 equivalent)
    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
2026-08-12 Add ModuleV491, a V490 with the unavailable parts replaced
    Four parts in the V490 BOMs are at zero stock at JLCPCB, so neither the
    monitoring board nor the balance daughterboard can be assembled as they
    stand. This adds them as a new revision rather than editing V490, so
    anything already built stays described by what is in the repo.
    Checked every LCSC code in both BOMs against the JLCPCB parts API on
    2026-08-12. Same footprint in every case, and the firmware is unchanged.
    Zero stock:
    U3 MCP33151-05-E/MS C635984 -> MCP33151-05T-E/MS C627094
    Same die, same MSOP-10; the T is tape-and-reel. The symbol in
    Module_16S.kicad_sch was already named for the T part - o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
    [Module_16S.kicad_pcb, Module_16S.kicad_sch, Module_16S_PassiveBalanceAddOn.kicad_pcb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]
2026-08-12 ESP8266 controller: R2 is still 4K7 in the PCB, 2K2 everywhere else
    R2 pulls the ESP8266's RX line (D7) to ground, and it was dropped from 4k7 to 2k2
    to fix intermittent comms errors between the controller and the modules - #59, and
    the forum thread it links to:
    https://community.openenergymonitor.org/t/workaround-for-the-communication-problems-change-resistor-in-controller/16388
    "I've just swapped my board to 2.2k and no issues, so will recommend that going
    forward"
    The schematic carries that: R2 is 2K2, with C17520 / 0805W8F2201T5E assigned to it
    in 922e88e. So do the netlist, the XML, the CSV and the JLCPCB BOM. The same
    change was made to the modules at the same time - Module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
    [ESP8266ControllerCircuit.kicad_pcb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]
2026-08-12 The EL3H7 optocoupler is not stocked at JLCPCB
    C32565 has been at zero stock for some time, so this board cannot be assembled as
    it stands. Replaced with AOTE's EL3H7B, C41371267, 20,414 in stock: same part
    number, same CTR rank B, same SSOP-4 on a 1.27mm pitch, same -55 to +110C, so it
    drops into the existing footprint. Worth noting because the obvious-looking
    alternatives do not - EL357, TLP185 and LTV-357T are all 2.54mm pitch DIP-4.
    The schematic and the JLCPCB BOM are both edited here. Unlike the ESP32 controller
    this board has no pcb-artifacts workflow, so its BOM is committed by hand.
    Its .csv, .xml and .net are older still - the netlist has this part as HMHA2801 and
    D1 as a 5mm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
    [ESP8266ControllerCircuit.sch, ESP8266ControllerCircuit_bom_jlc.csv]
2026-08-12 Five parts on the controller cannot be ordered as they stand
    Checked every LCSC code in this board's BOM against the JLCPCB parts API. Three of
    these are discontinued rather than merely out of stock - the parts API returns them
    with "停产" in the name, so waiting will not help.
    C3,C4 22uF 6.3V tantalum C110786 discontinued, 0 in stock
    -> C7182 Kyocera AVX TAJA226K006RNJ, 12,926 in stock
    same CASE-A-3216-18 outline, same 22uF 6.3V
    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
    [ControllerCircuit.kicad_sch]
2026-08-12 V421: neither of its two unstocked parts changes anything
    Both are drop-in.
    ATTINY841 C219103 0 in stock
    -> C614879 same die, same SOIC-14; the trailing R is tape and reel
    U1 EL3H7 C32565 0 in stock
    -> C41371267 AOTE's EL3H7B, same part number, same CTR rank B, same
    SSOP-4 on a 1.27mm pitch, same -55 to +110C
    Worth saying explicitly because the other legacy module is not in this position:
    V440 carries AZ432 for its reference and that part is discontinued with no 1.250V
    replacement, so it cannot be reproduced exactly. V421 uses TL432CSF (C126100),
    which is still stocked, so nothing about its behaviour moves.
    [ModuleV421.sch]
2026-08-12 V440: the two drop-in parts only - D1 stays AZ432 and has to be hand fitted
    SSOP-4 1.27mm, same -55 to +110C
    D1 is deliberately left alone. AZ432 (C84139) is discontinued - the Diodes
    datasheet is stamped OBSOLETE - USE AZ431L and DigiKey lists it as "no longer
    manufactured" - and every SOT-23 shunt reference still stocked is 1.240V: the
    TLV431 family, and AZ431L itself. There is no 1.250V part left.
    Substituting AZ431L would make this a differ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
    [ModuleV440.sch]
2026-08-12 V450: three parts, and D1 stays AZ432 so the board is unchanged
    -> C41371267 AOTE EL3H7B, same part number, CTR rank and SSOP-4
    Q1.. AO3400A C347475 Extended, in stock
    -> C20917 same part number, Basic, 1.4M in stock
    This is the same swap made on the V490 passive
    balancer; V450 was left behind
    D4 green LED C72043 discontinued, 1 in stock
    -> C7429914 NationStar NCD0603G3, emerald green like the
    original: 520-538nm against 520-535nm
    D4 took some picking. NationStar make three emerald green 0603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
    [ModuleV450.sch]
2026-08-12 Current shunt: the BOM puts two part numbers in one cell
    export/ControllerCurrentShuntAddOn_bom_jlc.csv has
    "100nF 100V","C1,C3","C_0805_2012Metric","C696367 C49678"
    and JLCPCB cannot read that cell. The board cannot be ordered as it stands, and
    this has nothing to do with stock - both parts are available.
    C1 and C3 are genuinely different parts. C1 is a 100V KEMET C0805C104K1RECAUTO
    (C696367) on the shunt input; C3 is an ordinary 100nF YAGEO CC0805KRX7R9BB104
    (C49678). They share a footprint, and the BOM groups them anyway, so the part
    number column ends up holding both codes with a space between.
    Fixed in the KiBot config rather than the generated file, which is what #100 was
    turn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
2026-08-12 Say what this branch is for
    Eight of the eleven boards in this repository cannot be ordered from JLCPCB as they
    stand. That is nothing to do with LTO or with any particular chemistry - it lands on
    anyone who tries to build one today - and it is not visible until you paste a BOM
    into the ordering page and it comes back rejected.
    This says which boards, what was changed, and which two cannot be reproduced exactly
    however the BOM is edited.
2026-08-12 V490: ten part numbers, all like-for-like
    Monitor board:
    U11 AP2204K-5.0TRG1 C112031 discontinued
    -> C5378676 AP2205-50W5-7, the Diodes successor, same
    SOT-23-5, same 5V/200mA
    U3 MCP33151-05 C635984 0 in stock
    -> C627094 same part, the T is tape and reel
    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
    [Module_16S.kicad_sch, PassiveBalancer.kicad_sch, PowerSupply.kicad_sch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]
2026-08-12 V400: give it part numbers so a BOM can be generated at all
    This is the only board here with no BOM and no CPL, and the reason is that its
    schematic carries no LCSCStockCode fields. Its parts were tracked in a separate
    spreadsheet, CellModules_LCSC_BillOfMaterials.xlsx, which is a purchase record
    rather than something any tool reads. Upstream only started putting part numbers
    in the schematics from V4.10 onwards.
    The 22 codes in that spreadsheet are transcribed into the schematic, matched to
    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
    [v4.sch]

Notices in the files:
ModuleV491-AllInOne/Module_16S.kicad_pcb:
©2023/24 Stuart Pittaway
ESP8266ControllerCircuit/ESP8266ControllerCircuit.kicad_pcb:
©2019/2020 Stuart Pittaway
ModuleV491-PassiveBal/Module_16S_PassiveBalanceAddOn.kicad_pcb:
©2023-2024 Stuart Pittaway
